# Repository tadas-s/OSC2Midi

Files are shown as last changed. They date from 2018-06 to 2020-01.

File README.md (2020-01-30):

# OSC2Midi

ESP8266 based OSC <-> Midi wireless bridge.

It is mostly meant to be used with [TouchOSC][1] but it will work with
any [OSC message source][2].

## Library dependencies

Project uses:
  * https://github.com/FortySevenEffects/arduino_midi_library/
  * https://github.com/CNMAT/OSC

## Hardware

Based on a generic ESP8266-12f board and the following guides to hook
up ESP8266 and do MIDI i/o:

  * [MIDI Input][4]
  * [MIDI Output][3]

Midi I/O uses [SoftwareSerial][5] mostly to allow debug logging via
primary serial port.

## Schematic

Note! Do checkout the KiCad project instead. Image below is for quick preview only.

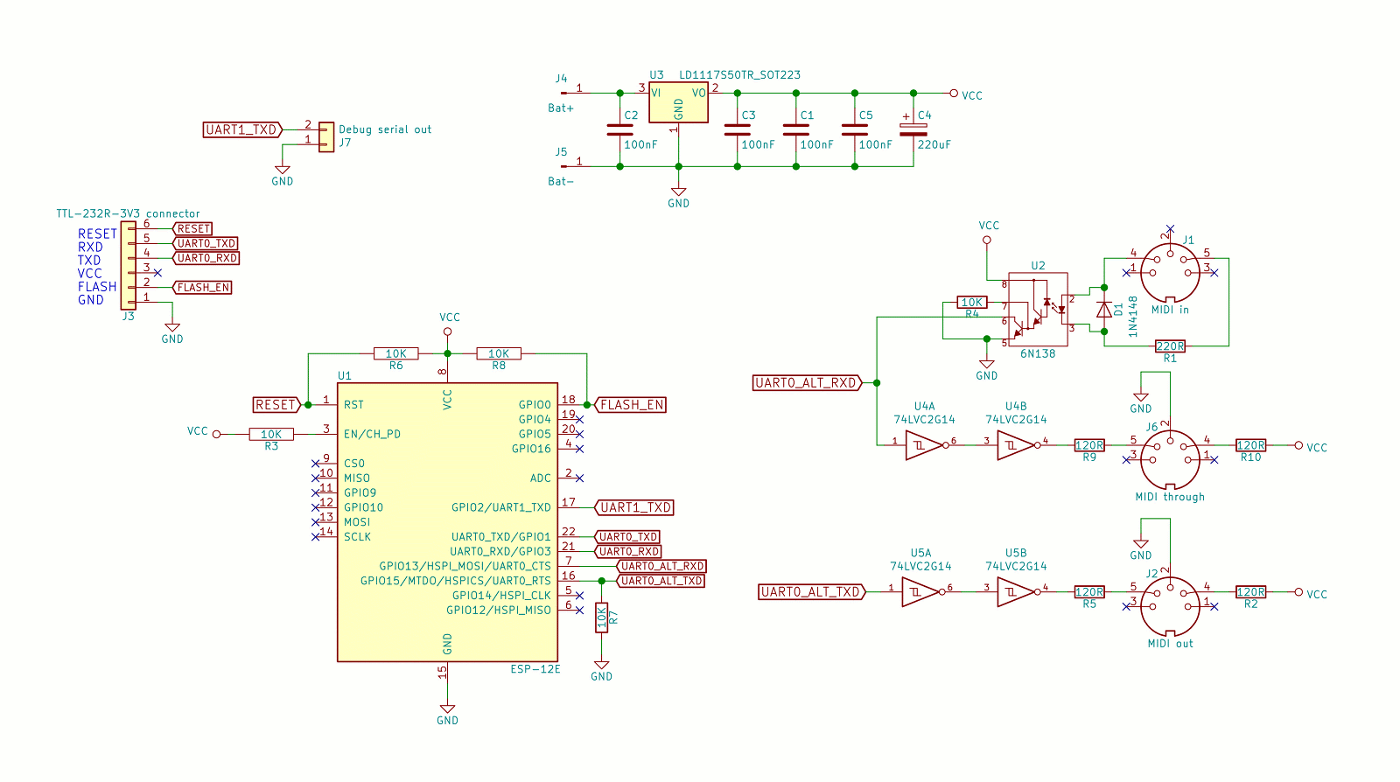
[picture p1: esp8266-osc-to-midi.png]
ESP8266 OSC to MIDI


## Flashing firmware

To flash the firmware I'm using FTDI cable with [flash+reset circuit][8].

## Hardware ideas / roadmap / TODO

  * Find a reasonable enclosure and adapt layout to it.
  * [MCP73833][7] based battery charging circuit + microusb input for power.
  * Maaaaybe i2c screen.

## OSC message formats

All messages are expected to have payload of 1 or 2 floats with range
from 0 to 127.

### /midi/cc/{cc} + 1 float

Will send control change message for `{cc}` number.

### /midi/cc/{ccA}/{ccB}/.../{index} + 1 float

Will send control change message for CC specified by `{index}`. For
example:

  * /midi/cc/10/12/15/1 -> CC to 10
  * /midi/cc/10/12/15/3 -> CC to 15

This is meant to be used with TouchOSC groups of faders. For example,
my [MicroKORG][6] preset includes a fader group of 4 to control
amp ADSR: `/midi/cc/73/75/70/72`

### /midi/cc/{ccA}/{ccB} + 2 floats

This sends two control change messages to `{ccA}` and `{ccB}`. This is
meant to be used with TouchOSC XY pads.

## Current prototype

Rather crude build, but it works:

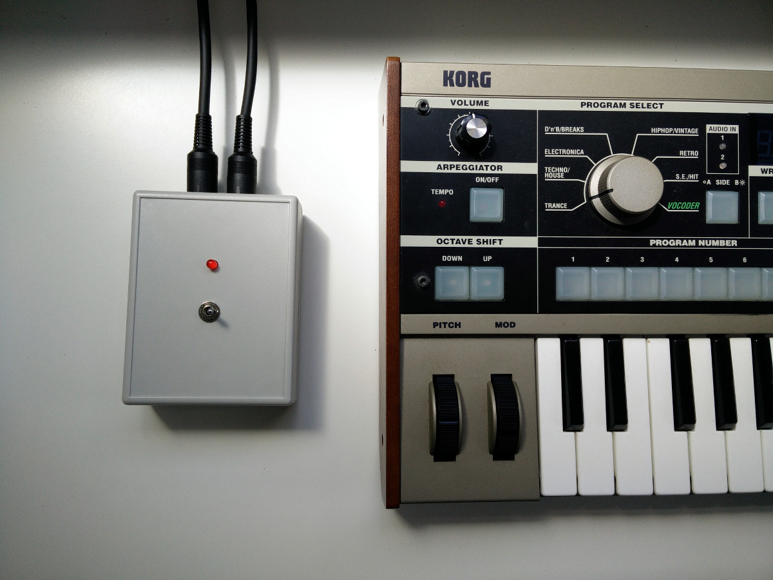
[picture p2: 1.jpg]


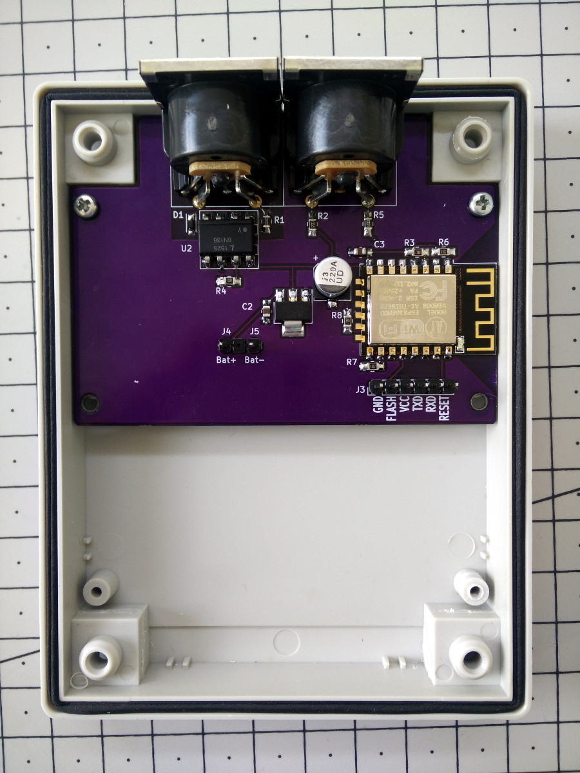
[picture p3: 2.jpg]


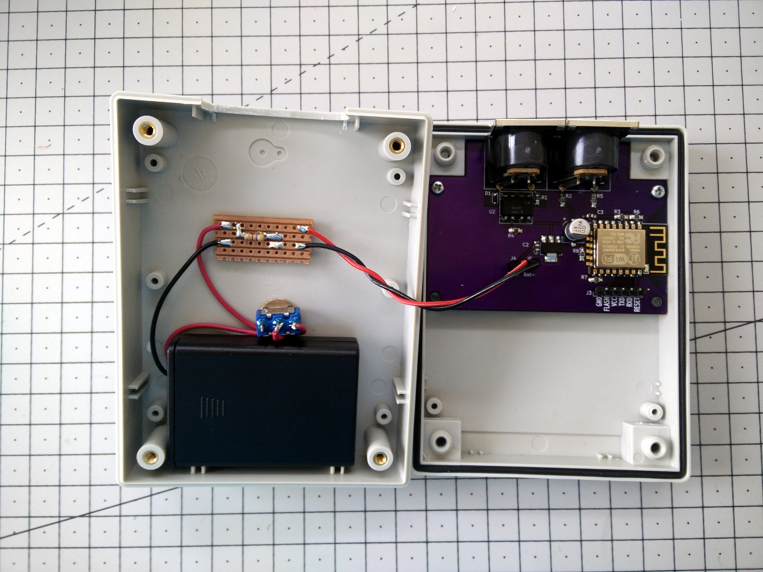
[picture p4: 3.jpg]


## Hello people of the future

So it seems GitHub is about to take a snapshot of active open source repositories
and put it into cold storage that should last 1000 years. Hence this section:
a change for the sake of it. Exact criteria is not clear, but hope this
repository makes it to the archive.

[1]: http://hexler.net/software/touchosc
[2]: https://en.wikipedia.org/wiki/Open_Sound_Control
[3]: https://www.arduino.cc/en/Tutorial/Midi
[4]: http://libremusicproduction.com/tutorials/arduino-and-midi-in
[5]: https://www.arduino.cc/en/Reference/SoftwareSerial
[6]: http://www.korg.com/us/products/synthesizers/microkorg/
[7]: https://www.microchip.com/wwwproducts/en/en027785
[8]: https://github.com/tadas-s/esp8266-autoreset

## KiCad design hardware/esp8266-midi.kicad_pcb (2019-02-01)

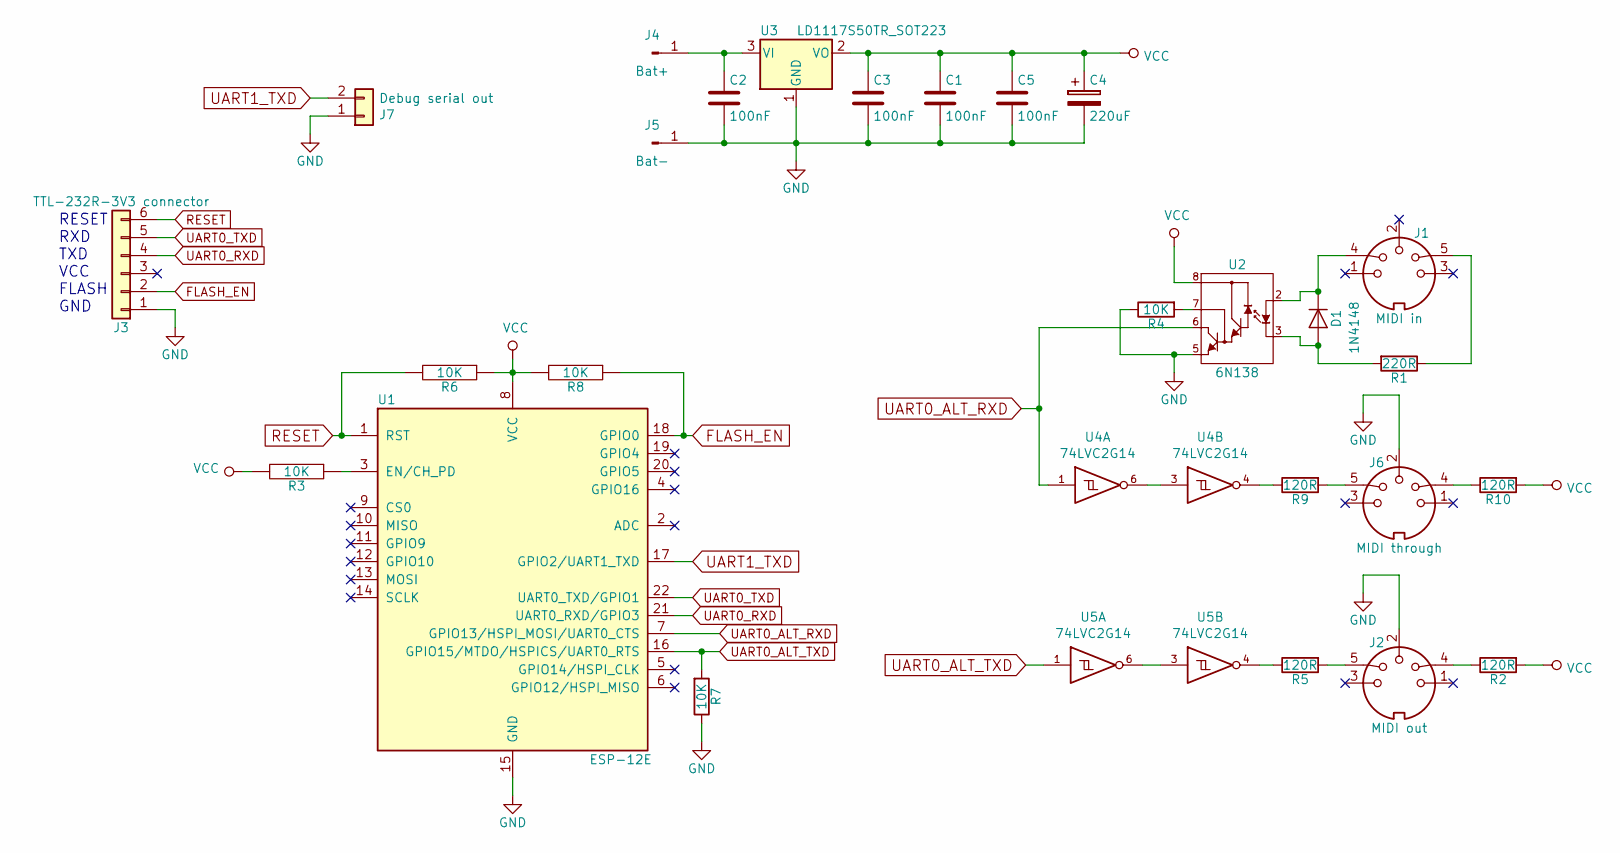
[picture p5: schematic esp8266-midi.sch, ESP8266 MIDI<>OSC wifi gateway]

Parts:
C1, C2, C3, C5: 100nF; C_0805_HandSoldering
C4: 220uF; CP_Elec_6.3x5.8
D1: 1N4148; D_SOD-323_HandSoldering
J1: MIDI in; SDS-50J
J2: MIDI out; SDS-50J
J3: TTL-232R-3V3 connector; Pin_Header_Straight_1x06_Pitch2.54mm
J4: Bat+; SolderWirePad_single_0-8mmDrill
J5: Bat-; SolderWirePad_single_0-8mmDrill
J6: MIDI through; SDS-50J
J7: Debug serial out; Pin_Header_Straight_1x02_Pitch2.54mm
R1: 220R; R_0805_HandSoldering
R2, R5, R9, R10: 120R; R_0805_HandSoldering
R3, R4, R6, R7, R8: 10K; R_0805_HandSoldering
U1: ESP-12E
U2: 6N138; DIP-8_W7.62mm_SMDSocket_SmallPads
U3: LD1117S50TR_SOT223; SOT-223
U4, U5: 74LVC2G14; SOT-23-6_Handsoldering

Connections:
FLASH_EN: J3.2, R8.1, U1.18 (GPIO0)
GND: C1.2, C2.2, C3.2, C4.2, C5.2, J2.2, J3.1, J5.1, J6.2, J7.1, R4.1, R7.1, U1.15 (GND), U2.5 (GND), U3.1 (GND), U4.2 (GND), U5.2 (GND)
unnamed: C2.1, J4.1, U3.3 (VI)
unnamed: D1.1 (K), J1.4, U2.2 (A)
unnamed: D1.2 (A), R1.2, U2.3 (K)
unnamed: J1.5, R1.1
unnamed: J2.4, R2.1
unnamed: J2.5, R5.2
unnamed: J6.4, R10.1
unnamed: J6.5, R9.2
unnamed: R3.1, U1.3 (EN/CH_PD)
unnamed: R4.2, U2.7 (Vb)
unnamed: R5.1, U5.4
unnamed: R9.1, U4.4
unnamed: U4.3, U4.6
unnamed: U5.3, U5.6
RESET: J3.6, R6.2, U1.1 (RST)
UART0_ALT_RXD: U1.7 (GPIO13/HSPI_MOSI/UART0_CTS), U2.6 (Vo), U4.1
UART0_ALT_TXD: R7.2, U1.16 (GPIO15/MTDO/HSPICS/UART0_RTS), U5.1
UART0_RXD: J3.4, U1.21 (UART0_RXD/GPIO3)
UART0_TXD: J3.5, U1.22 (UART0_TXD/GPIO1)
UART1_TXD: J7.2, U1.17 (GPIO2/UART1_TXD)
VCC: C1.1, C3.1, C4.1, C5.1, R2.2, R3.2, R6.1, R8.2, R10.2, U1.8 (VCC), U2.8 (Vcc), U3.2 (VO), U4.5 (VCC), U5.5 (VCC)

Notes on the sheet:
RESET RXD TXD VCC FLASH GND

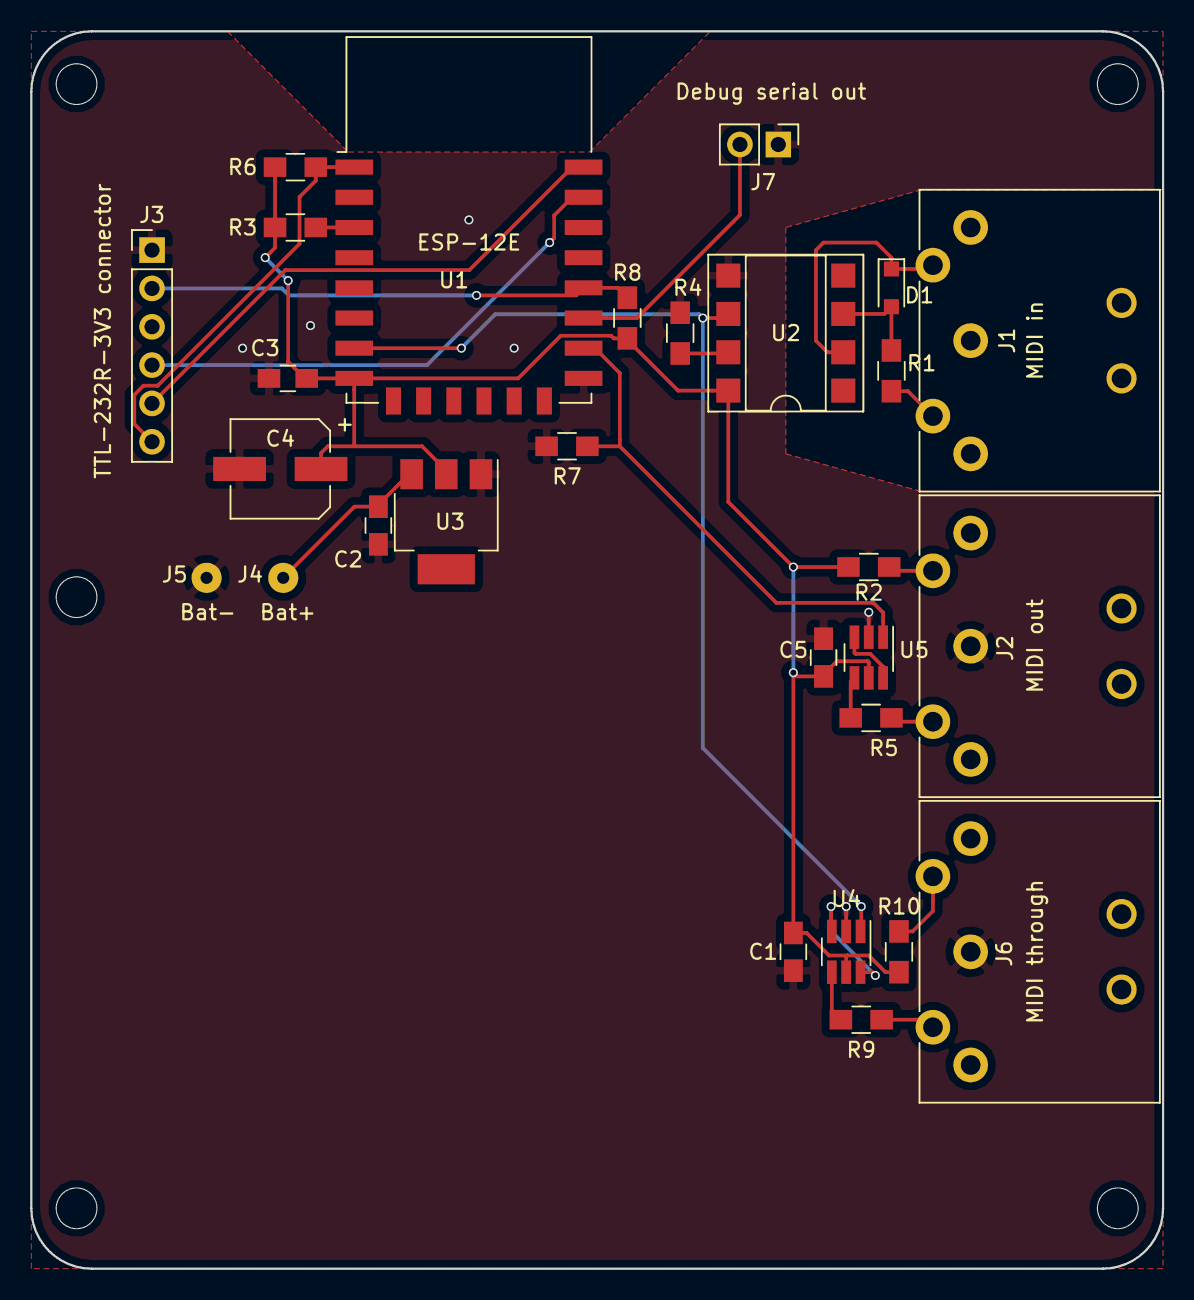
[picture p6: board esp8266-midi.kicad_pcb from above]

Board: 2 copper layers, 75.0 x 82.0 mm, 28 parts (0 on the bottom side), 23 nets.

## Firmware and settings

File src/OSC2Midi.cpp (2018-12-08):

#include <Arduino.h>
#include <ESP8266WiFi.h>
#include <WiFiUdp.h>
#include <OSCMessage.h>
#include <OSCBundle.h>
#include <OSCData.h>
#include <SoftwareSerial.h>
#include <MIDI.h>
#include <OSC2Midi.h>
#include "debug.h"

void MidiCCToOSC(uint8_t channel, uint8_t number, uint8_t value);

WiFiUDP udp;

/**
   source address of last OSC message for midi2osc messages.
*/
IPAddress clientIP;

SoftwareSerial midiSerialPort(4, 5); // RX, TX pins to be used for ss port

MIDI_CREATE_INSTANCE(SoftwareSerial, midiSerialPort, MIDI);

// Built-in led used to show activity status
#define LED_BUILTIN 2
bool led = false;

void setup() {
  // The MIDI input used in project is always pulled high,
  // so don't try to "fight" and pull the input pin up as well
  pinMode(4, INPUT_PULLUP);
  pinMode(5, OUTPUT);
  pinMode(LED_BUILTIN, OUTPUT);

  Serial.begin(115200);

  DEBUG_MSG("\nHello OSC2Midi!\n");

  WiFi.softAP("OSC2Midi", "Midi2OSCGateway");

  DEBUG_MSG("\nAP IP address: %s\n", WiFi.softAPIP().toString().c_str());

  udp.begin(8000);

  MIDI.setHandleControlChange(MidiCCToOSC);

  midiSerialPort.begin(31250);
}

void OSCToMidiCC(OSCMessage &msg, int offset) {
  char address[100] = { 0 };
  uint8_t cc, value;

  msg.getAddress(address, offset, sizeof(address));

  if (msg.size() == 1 && msg.isFloat(0)) {
    // Single or multi control with sending one value
    cc = getCC(address);
    value = round(msg.getFloat(0));
    value = value > 127 ? 127 : value;
    DEBUG_MSG("MSG: %s\tCC: %u\tValue: %u\n", address, cc, value);
    MIDI.sendControlChange(cc, value, 1);
  } else if (msg.size() == 2 && msg.isFloat(0) && msg.isFloat(1)) {
    // XY pad, two values
    cc = getCC(address, 0);
    value = round(msg.getFloat(0));
    value = value > 127 ? 127 : value;
    DEBUG_MSG("MSG: %s\tCC: %u\tValue: %u\n", address, cc, value);
    MIDI.sendControlChange(cc, value, 1);

    cc = getCC(address, 1);
    value = round(msg.getFloat(1));
    value = value > 127 ? 127 : value;
    DEBUG_MSG("MSG: %s\tCC: %u\tValue: %u\n", address, cc, value);
    MIDI.sendControlChange(cc, value, 1);
  } else {
    DEBUG_MSG("Cannot handle: %s\n", address);
  }
}

void MidiCCToOSC(uint8_t channel, uint8_t number, uint8_t value) {
  char buffer[1024];
  snprintf(buffer, sizeof(buffer), "/midi/cc/%u", number);

  OSCMessage msg = OSCMessage(buffer);
  msg.add(value * 1.0);

  DEBUG_MSG("MidiCCToOsc: %s %f", buffer, value * 1.0);

  udp.beginPacket(clientIP, 8001);
  msg.send(udp);
  udp.endPacket();
}

void loop() {
  OSCMessage msg;
  uint8_t buffer[1024];

  // Check if there are any OSC packets to handle
  size_t size = udp.parsePacket();
  if (size > 0 && size <= 1024) {
    udp.read(buffer, size);
    msg.fill(buffer, size);

    if (!msg.hasError()) {
      msg.route("/midi/cc", OSCToMidiCC);
      led = !led;
      digitalWrite(LED_BUILTIN, led);
    } else {
      DEBUG_MSG("Error parsing OSC message: %d", msg.getError());
    }

    // Keep track of the client IP address for "talking back"
    clientIP = udp.remoteIP();
  }

  // Check if there are any CC messages from synth itself
  MIDI.read();
}

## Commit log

2018-03-08 Update README.md
    Mixed up links to midi in and out schematics
2018-03-10 Initial rev of schematic and PCB, WIP
    [esp8266-midi.kicad_pcb, esp8266-midi.sch]
2018-04-03 Misc: tweaks trying to figure out Android's "authentication error"
    Maybe it's the early start, maybe something else.. Or maybe persisted
    credentials from before?
    [OSC2Midi.ino]
2018-04-04 Update schematic: now uses ESP-12E footprint from standard KiCad lib
    + Misc silly fixes.
    [esp8266-midi.sch]
2018-04-04 Updated PCB using correct ESP-12E footprint
    [esp8266-midi.kicad_pcb]
2018-04-08 Schematic change: do not pull up opto-isolator output + change output resistor loop values
    1. Pull up can be done by the micro itself.
    2. 220 ohm examples are taken from Midi spec when voltage is 5v. To match the
    the same current when using 3.3v micro resistors were reduced to 120ohm.
    [esp8266-midi.sch]
2018-04-08 Hopefully fixed layout now
    [esp8266-midi.kicad_pcb]
2018-04-09 Before resizing the board a bit
    [esp8266-midi.kicad_pcb, esp8266-midi.sch]
2018-04-09 Small resize of the board + relocating some stuff + some rounded ground zone corners
    [esp8266-midi.kicad_pcb]
2018-04-24 Misc cleanup: remove some TODOs/notes. Schematic is verified / works.
    [esp8266-midi.sch]
2018-04-24 Not sure why but KiCad decided to update project file a bit...
2018-04-24 Add schematic preview to README.md
2018-05-29 Misc: re-freshed schematic preview
2018-06-02 Misc: change "candidate" enclosure to CRDCGG003 by CamdenBoss
2018-06-02 Misc: ditch the reset/flash minimum circuit diagram example
    Will be using external programming adapter with dtrset reset method.
2018-06-02 Change schematic to use external flash enable + reset circuit
    Less components + all those switches are expensive and cumbersome to use ;)
    And another misc change: remove a probs redundant power supply smoothing
    capacitor.
    [esp8266-midi.sch]
2018-06-02 Assign SMD footprints to (almost) all components
    [esp8266-midi.sch]
2018-06-03 New layout with (mostly) smd components, pcb shaped for CRDCGG003 enclosure
    [esp8266-midi.kicad_pcb]
2018-06-24 Pics of first crude prototype in enclosure
2018-11-10 Serial monitor: set speed + rts flag
    RTS pulled low is required so openning serial monitor does not reset the board
    in firmware flash mode.
2018-11-24 Kicad5: schematic after converting to kicad5, no other changes
    [esp8266-midi.sch]
2018-11-24 Kicad5: netlist after converting to kicad5
2018-11-24 Kicad5: pcb after converting to kicad5
    [esp8266-midi.kicad_pcb]
2018-12-05 Unit tests: rename main .ino file to .cpp, move stuff to be tested to a local lib
    This also switches from Arudino String class to standard c strings.
2018-12-07 Misc: add MIT license ... ¯\_(ツ)_/¯
2018-12-08 Rewrite debug statements to use DEBUG_MSG + some other misc changes
    Other miscalenous stuff:
    * Blink the built-in led to show activity
    * Ignore packets larger than buffer
2018-12-08 Schematic changes: midi through, midi via hardware serial, debug serial out
    [esp8266-midi.sch]
2018-12-08 Updated PCB with new components .. little questionable / not final.
    [esp8266-midi.kicad_pcb]
2018-12-08 Misc: swap debug output pins
    [esp8266-midi.sch]
2018-12-08 New pcb: with midi through, all 3 connectors are now on the side
    PCB will be mount flipped on top of enclosure. In future it will allow having
    pcb mount push buttons + display available on front of enclosure.
    [esp8266-midi.kicad_pcb]
2018-12-09 Misc: add some extra labels to have little more meaningful net names
    [esp8266-midi.kicad_pcb, esp8266-midi.sch]
2018-12-09 Misc: fix some 3d shape paths after upgrade to kicad5
    [esp8266-midi.kicad_pcb]
2018-12-15 Use uart0 for midi and uart1 for debug messages
    This ditches SoftwareSerial for which I suspect was causing crashes.
    This also ditches led blinking since built-in esp12e led is on the same pin as
    uart1 tx.
    [OSC2Midi.cpp]
2019-01-05 Use alternative uart0 pins for midi i/o
    uart0 pushes bunch of rubbish messages on boot up. This means some pretty random
    messages on the midi out port. To fix this midi i/o uses alternative uart0 pins
    which can be enabled after microcontroller is booted by calling 'Serial.swap()'.
    Alternative TX pin needs to be pulled down during boot, but a connected midi
    instrument pull it up. Therefore the buffering using the same dual nand
    (74LVC2G14) as for the midi through port.
    [esp8266-midi.kicad_pcb, esp8266-midi.sch]
2019-02-01 Kicad5 update woes again: eeschema rescues
    [esp8266-midi.sch]
2019-02-01 Kicad5 update woes again: netlist update
2019-02-01 Misc: fix ESP-12E 3d model path
    [esp8266-midi.kicad_pcb]
2019-02-01 Update README.md: schematic image
